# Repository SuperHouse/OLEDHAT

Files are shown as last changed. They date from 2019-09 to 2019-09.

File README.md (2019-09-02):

OLED / Voltage Regulator Hat for Raspberry Pi
==============================================
Copyright 2019 SuperHouse Automation Pty Ltd www.superhouse.tv  

FEATURES
--------

 * 128x64 1.3" OLED with I2C interface.
 * Menu buttons with I2C interface using MCP23017.
 * Supply power via 2.1mm DC jack or the PoE header on Raspberry Pi 3
   B+/4. Regulates down to 5V to supply the Raspberry Pi.

INSTALLATION
------------
The design is saved as an EAGLE project. EAGLE PCB design software is
available from www.cadsoftusa.com free for non-commercial use. To use
this project download it and place the directory containing these files
into the "eagle" directory on your computer. Then open EAGLE and
navigate to the project.

CREDITS
-------
Designed by Jonathan Oxer <jon@oxer.com.au>

DISTRIBUTION
------------
The specific terms of distribution of this project are governed by the
license referenced below.

LICENSE
-------
Licensed under the TAPR Open Hardware License (www.tapr.org/OHL).
The "license" folder within this repository also contains a copy of
this license in plain text format.

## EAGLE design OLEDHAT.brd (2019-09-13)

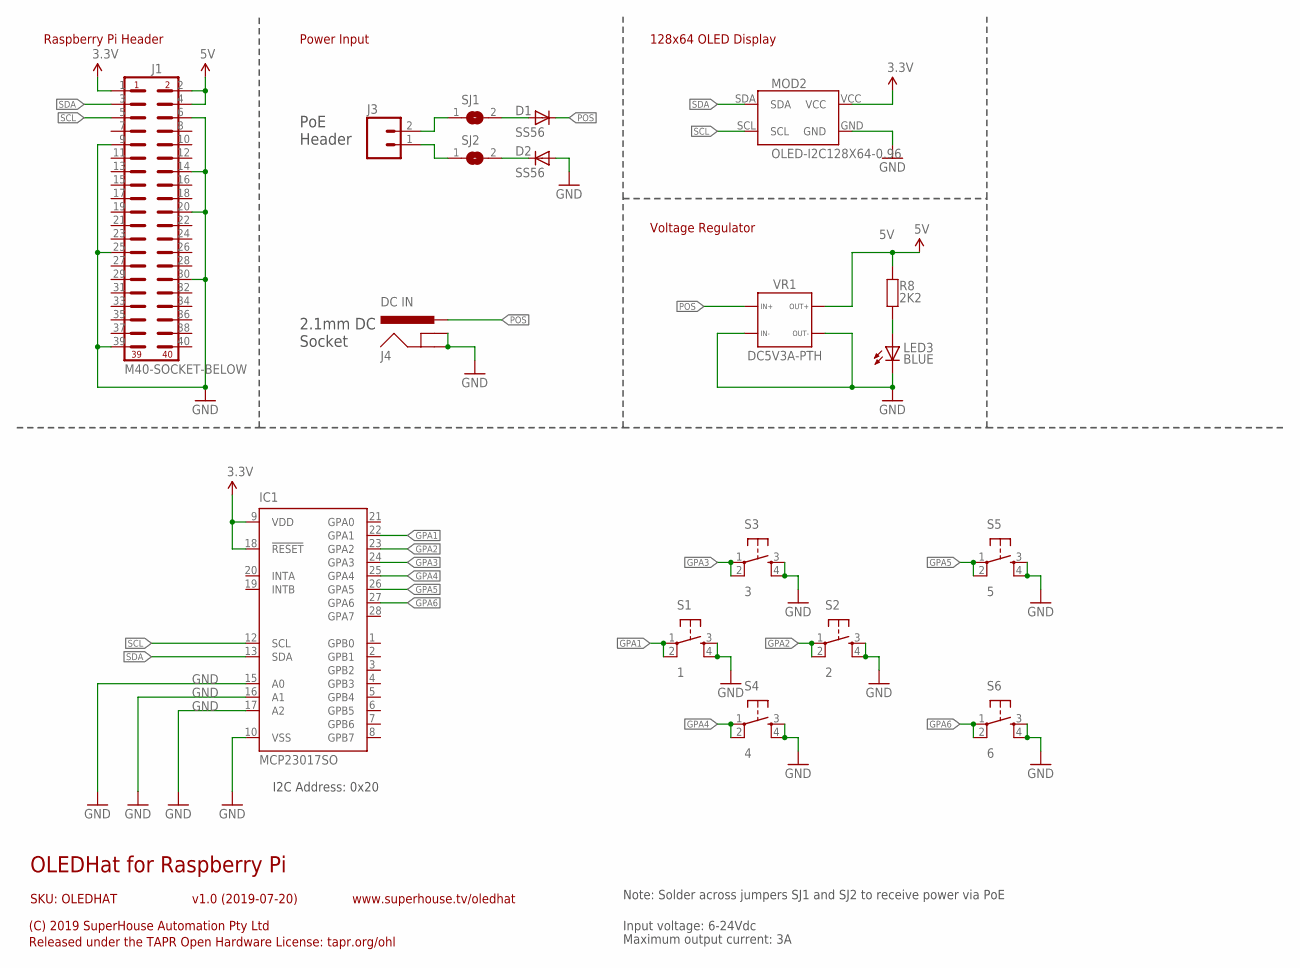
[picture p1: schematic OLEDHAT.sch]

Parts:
D1, D2: SS56; SMA-DIODE
IC1: MCP23017SO; SO28W
J1: M40-SOCKET-BELOW; 2X20-S-BELOW
J3: M02-SOCKET-BELOW; 1X02-S-BELOW
J4: DC IN; POWER_JACK_SLOTS
LED3: BLUE; LED-0603
MOD2: OLED-I2C128X64-0.96; OLED-128X64-0.96
R8: 2K2; R0603
S1: 1; TACTILE-PTH-4.5MM
S2: 2; TACTILE-PTH-4.5MM
S3: 3; TACTILE-PTH-4.5MM
S4: 4; TACTILE-PTH-4.5MM
S5: 5; TACTILE-PTH-4.5MM
S6: 6; TACTILE-PTH-4.5MM
SJ1, SJ2: SJN; SJ
VR1: DC5V3A-PTH

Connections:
3.3V: IC1.9 (VDD), IC1.18 (!RESET), J1.1, MOD2.VCC
5V: J1.2, J1.4, R8.1, VR1.3A (3), VR1.3B (3)
GND: D2.A, IC1.10 (VSS), IC1.15 (A0), IC1.16 (A1), IC1.17 (A2), J1.6, J1.9, J1.14, J1.20, J1.25, J1.30, J1.39, J4.GND, J4.GNDBREAK, LED3.C, MOD2.GND, S1.3, S1.4, S2.3, S2.4, S3.3, S3.4, S4.3, S4.4, S5.3, S5.4, S6.3, S6.4, VR1.1A (1), VR1.1B (1), VR1.4A (4), VR1.4B (4)
GPA1: IC1.22 (GPA1), S1.1, S1.2
GPA2: IC1.23 (GPA2), S2.1, S2.2
GPA3: IC1.24 (GPA3), S3.1, S3.2
GPA4: IC1.25 (GPA4), S4.1, S4.2
GPA5: IC1.26 (GPA5), S5.1, S5.2
GPA6: IC1.27 (GPA6), S6.1, S6.2
unnamed: J3.1, SJ2.1
unnamed: J3.2, SJ1.1
unnamed: D1.A, SJ1.2
unnamed: D2.C, SJ2.2
unnamed: LED3.A, R8.2
POS: D1.C, J4.PWR, VR1.2A (2), VR1.2B (2)
SCL: IC1.12 (SCL), J1.5, MOD2.SCL
SDA: IC1.13 (SDA), J1.3, MOD2.SDA

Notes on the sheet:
OLEDHat for Raspberry Pi
v1.0 (2019-07-20)
(C) 2019 SuperHouse Automation Pty Ltd
Released under the TAPR Open Hardware License: tapr.org/ohl
www.superhouse.tv/oledhat
SKU: OLEDHAT
Raspberry Pi Header
Input voltage: 6-24Vdc
Maximum output current: 3A
PoE Header
2.1mm DC Socket
Power Input
128x64 OLED Display
Voltage Regulator
Note: Solder across jumpers SJ1 and SJ2 to receive power via PoE
I2C Address: 0x20

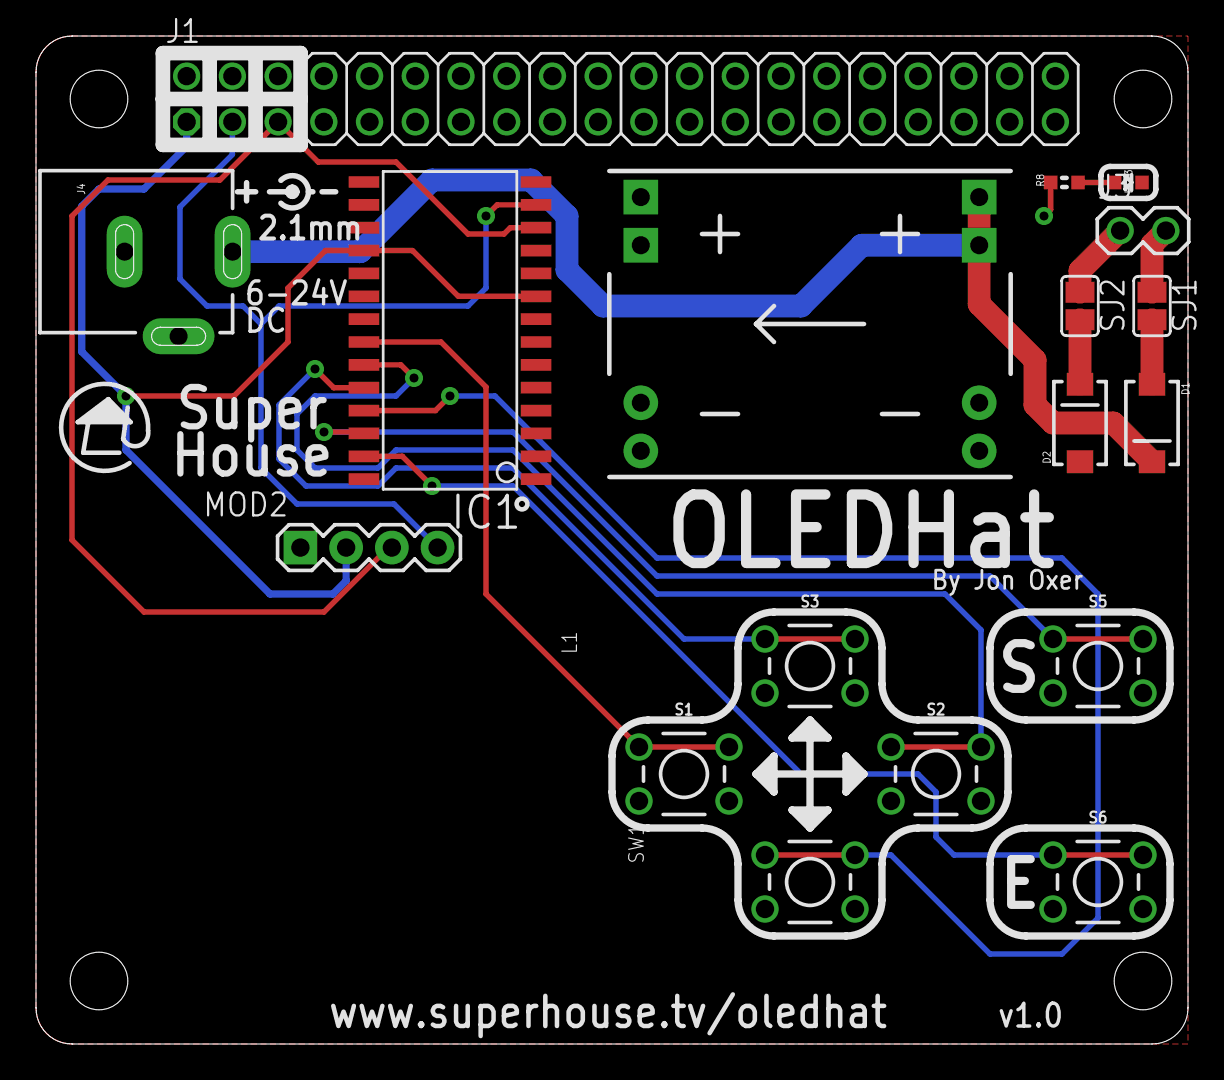
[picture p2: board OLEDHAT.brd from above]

Board: 2 copper layers, 64.0 x 56.0 mm, 18 parts (0 on the bottom side), 17 nets.

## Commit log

2019-09-02 Migrated project files
    [OLEDHAT.brd, OLEDHAT.sch, VOLTHAT.brd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]
2019-09-13 Final routing, plus ERC and DRC for v1.0 release
    [OLEDHAT.brd, OLEDHAT.sch]
